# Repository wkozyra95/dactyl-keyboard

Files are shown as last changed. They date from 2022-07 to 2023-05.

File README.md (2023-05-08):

# The Dactyl-ManuForm Keyboard

This fork is just for my personal customizations, it removes a lot of features of the [original project](https://github.com/tshort/dactyl-keyboard).

## Third iteration



**.scad** and **.stl** files can be found in [./things/03-iteration](/things/03-iteration).

- `right.stl` and `left.stl` represents 2 halves of split keyboard. IO of each part includes:
  - Output to expose usb-c or micro usb port for charging and flushing firmware.
  - 2-position switch for controlling power for keyboard.
  - Reset button.
- `dongle.stl` is a case for nice nano that is main controller (nice!nano v2.0) for both parts of the keyboards.
- `plate.dxf` describes 2D shape of a bottom plate that case is mounted on.
- `platev2.dxf` plate variant with a cut-out in the middle intended for charging coil for wireless charging.

Communication between all the parts is handled by a nice!nano controller in a dongle. Both parts of the keyboard have it's own nice!nano controllers that connect to a dongle via bluetooth. This approach enables using this keyboard wirelessly before bluetooth is on e.g. in BIOS, or to provide LUKS password.

Power for all parts is provided via usb, but both keyboard halves also include batteries that should enable few weeks of work without recharging. Main controller has to always listen for bluetooth communication from other parts. This is increasing power usage when compared to secondary parts, so it's best to use dongle for that, which is always is connected via usb.

## Second iteration



**.scad** and **.stl** files can be found in [./things/02-iteration](/things/02-iteration).

## First iteration



**.scad** and **.stl** files can be found in [./things/01-iteration](/things/01-iteration).

# README from original repo

This is a fork of the [Dactyl](https://github.com/adereth/dactyl-keyboard), a parameterized, split-hand, concave, columnar, ergonomic keyboard.

Imgur

The main change is that the thumb cluster was adapted from the [ManuForm keyboard](https://github.com/jeffgran/ManuForm) ([geekhack](https://geekhack.org/index.php?topic=46015.0)). The walls were changed to just drop to the floor. The keyboard is paramaterized to allow adjusting the following:

* Rows: 4 - 6
* Columns: 5 and up
* Row curvature
* Column curvature
* Row tilt (tenting)
* Column tilt
* Column offsets
* Height

I built a 4x5 version (40% size) for myself. The default has a bit more tenting than the Dactyl. See the following model files for configurations that may be most common:

* [40% size, (4x5)](https://github.com/tshort/dactyl-keyboard/blob/master/things/right-4x5.stl)
* [60% size, (5x6)](https://github.com/tshort/dactyl-keyboard/blob/master/things/right-5x6.stl)

## Assembly

### Generating a Design

**Setting up the Clojure environment**
* [Install the Clojure runtime](https://clojure.org)
* [Install the Leiningen project manager](http://leiningen.org/)
* [Install OpenSCAD](http://www.openscad.org/)

**Generating the design**
* Run `lein repl`
* Load the file `(load-file "src/dactyl_keyboard/dactyl.clj")`
* This will regenerate the `things/*.scad` files
* Use OpenSCAD to open a `.scad` file.
* Make changes to design, repeat `load-file`, OpenSCAD will watch for changes and rerender.
* When done, use OpenSCAD to export STL files

**Tips**
* [Some other ways to evaluate the clojure design file](http://stackoverflow.com/a/28213489)
* [Example designing with clojure](http://adereth.github.io/blog/2014/04/09/3d-printing-with-clojure/)

### Printing
Pregenerated STL files are available in the [things/](things/) directory.
When a model is generated, it also generates a `.scad` model for a bottom plate.
This can be exported to a DXF file in OpenSCAD.
The [things/](things/) directory also has DXF files for the bottom plate.
When laser cut, some of the inside cuts will need to be removed.

This model can be tricky to print.
It's wide, so I've had problems with PLA on a Makerbot with edges warping.
This can cause the printer to think its head is jammed.
Even if it successfully prints, warping can cause problems.
On one print, the RJ-9 holder was squished, so I had to cut down my connector to fit.

If printed at Shapeways or other professional shops, I would not expect such problems.

### Thingiverse

[The 4x5 STL left/right pair](https://www.thingiverse.com/thing:2349390) from the [things/](things/) directory is in the thingiverse for public printing

### Wiring

Here are materials I used for wiring.

* Two Arduino Pro Micros
* [Heat-set inserts](https://www.mcmaster.com/#94180a331/=16yfrx1)
* [M3 wafer-head screws, 5mm](http://www.metricscrews.us/index.php?main_page=product_info&cPath=155_185&products_id=455)
* [Copper tape](https://www.amazon.com/gp/product/B009KB86BU)
* [#32 magnet wire](https://www.amazon.com/gp/product/B00LV909HI)
* [#30 wire](https://www.amazon.com/gp/product/B00GWFECWO)
* [3-mm cast acrylic](http://www.mcmaster.com/#acrylic/=144mfom)
* [Veroboard stripboard](https://www.amazon.com/gp/product/B008CPVMMU)
* [1N4148 diodes](https://www.amazon.com/gp/product/B00LQPY0Y0)
* [Female RJ-9 connectors](https://www.amazon.com/gp/product/B01HU7BVDU/)

I wired one half using the traditional approach of using the legs of a diode to form the row connections.
(I'm not great at soldering, so this was challenging for me.)
For this side, I used magnet wire to wire columns. That worked okay.
The magnet wire is small enough, it wants to move around, and it's hard to tell if you have a good connection.

Imgur

For another half, I used stripboard for the row connections.
This allowed me to presolder all of the diodes.
Then, I hot-glued this in place and finished the soldering of the other diode ends.
I like this approach quite a lot.
Connections for the diodes were much easier with one end fixed down.
On this half, I also used copper tape to connect columns.
This worked a bit better than the magnet wire for me.
For a future version, I may try just bare tinned copper wire for columns (something like #20).
With the stripboard, it's pretty easy keeping row and column connections separate.

Imgur

Note that a telephone handset cable has leads that are reversed, so take this into account when connecting these leads to the controller.

The 3D printed part is the main keyboard.
You can attach a bottom plate with screws.
The case has holes for heat-set inserts designed to hold 3- to 6-mm long M3 screws.
Then, I used wafer-head screws to connect a bottom plate.
If wires aren't dangling, a bottom plate may not be needed.
You need something on the bottom to keep the keyboard from sliding around.
Without a plate, you could use a rubber pad, or you could dip the bottom of the keyboard in PlastiDip.

For more photos of the first complete wiring of v0.4, see [Imgur](http://imgur.com/a/v9eIO).

This is how the rows/columns wire to the keys and the ProMicro
Wire Diagram

#### Alternative row-driven wiring diagram for ProMicro:

NOTE: you also make sure the firmware is set up correctly (ex: change row pins with col pins)

Left Wire Diagram

Left Wire Diagram

### Firmware

Firmware goes hand in hand with how you wire the circuit.
I adapted the QMK firmware [here](https://github.com/tshort/qmk_firmware/tree/master/keyboards/dactyl-manuform).
This allows each side to work separately or together.
This site also shows connections for the Arduino Pro Micro controllers.

## License

Copyright © 2015-2017 Matthew Adereth and Tom Short

The source code for generating the models (everything excluding the [things/](things/) and [resources/](resources/) directories is distributed under the [GNU AFFERO GENERAL PUBLIC LICENSE Version 3](LICENSE).  The generated models and PCB designs are distributed under the [Creative Commons Attribution-NonCommercial-ShareAlike License Version 3.0](LICENSE-models).

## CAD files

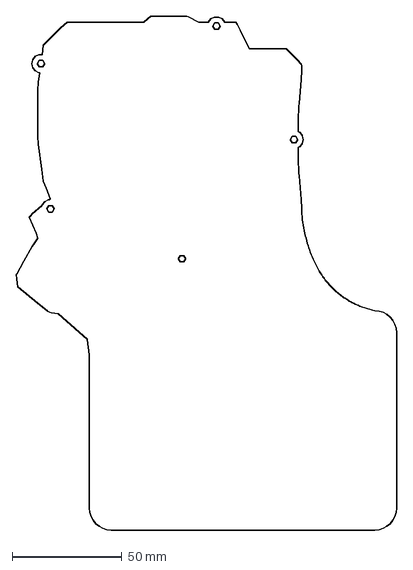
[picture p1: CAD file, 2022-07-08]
things/01-iteration/plate-v2.dxf
173.3 x 234.3 mm

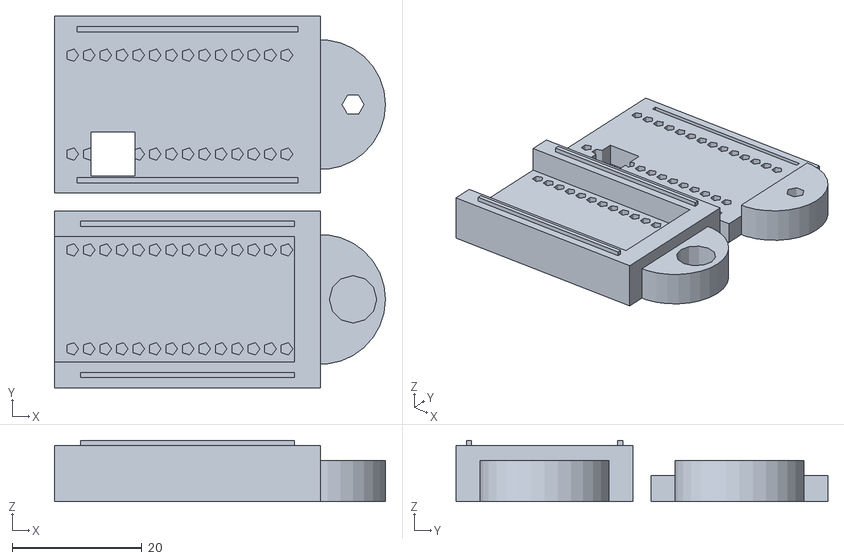
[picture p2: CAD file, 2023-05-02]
things/03-iteration/donglev2.stl
51.0 x 57.3 x 9.44

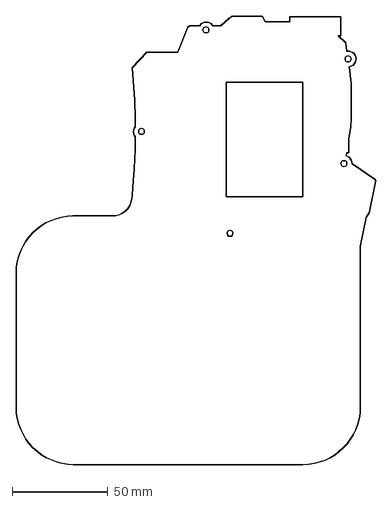
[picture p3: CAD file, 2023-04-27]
things/03-iteration/platev2.dxf
188.2 x 234.3 mm

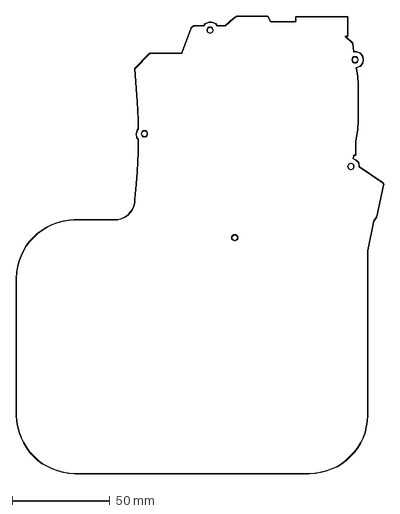
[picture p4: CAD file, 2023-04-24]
things/03-iteration/plate.dxf
188.2 x 234.3 mm

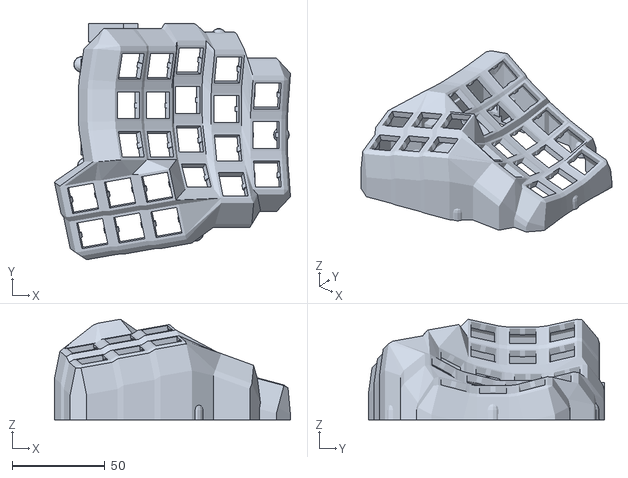
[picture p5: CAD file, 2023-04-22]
things/03-iteration/right.stl
127.4 x 127.7 x 54.3

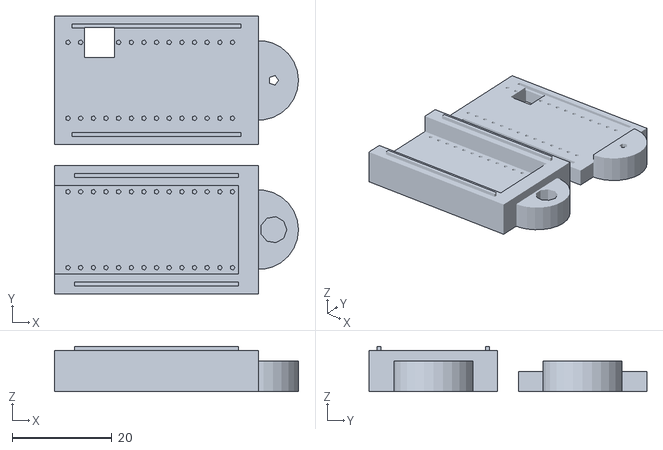
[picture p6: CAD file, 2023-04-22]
things/03-iteration/dongle.stl
49.0 x 55.8 x 9.04

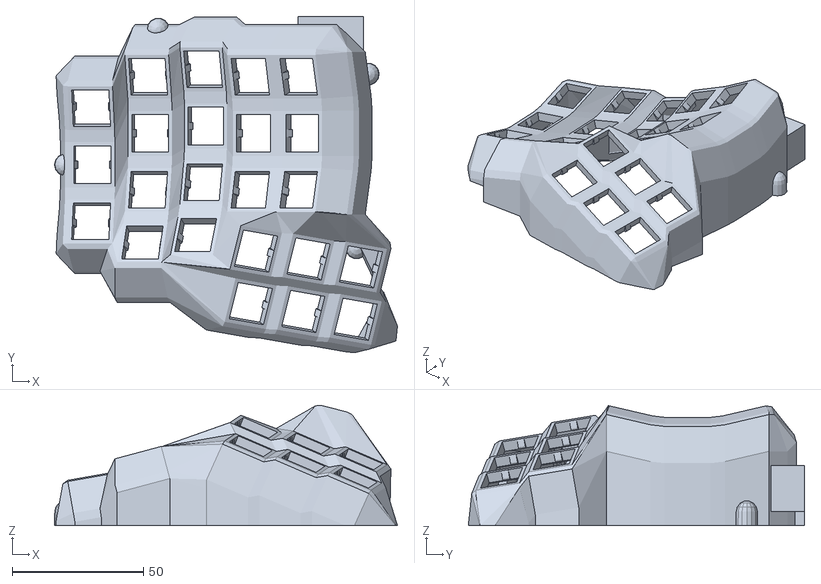
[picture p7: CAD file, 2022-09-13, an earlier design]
things/02-iteration/left.stl
130.8 x 128.3 x 45.8

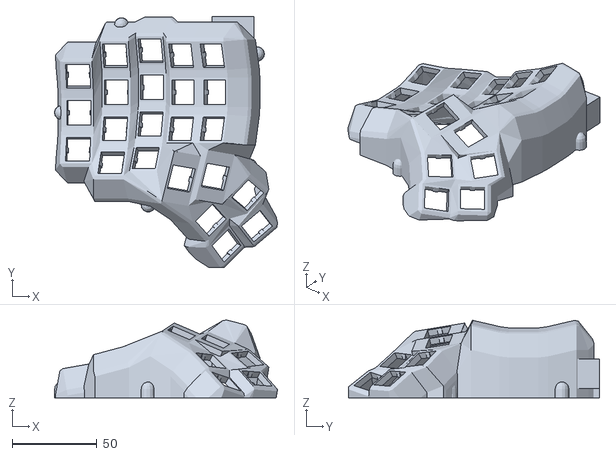
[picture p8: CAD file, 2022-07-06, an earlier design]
things/left.stl
131.5 x 147.9 x 45.8

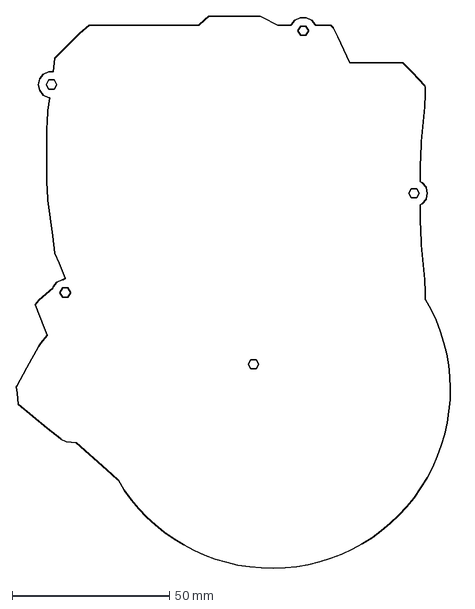
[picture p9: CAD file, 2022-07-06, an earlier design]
things/01-iteration/plate-v1.dxf
140.6 x 175.7 mm

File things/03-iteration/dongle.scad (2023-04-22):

union () {
  translate ([0, 30, 0]) {
    union () {
      translate ([0, 0, 3.06]) {
        translate ([41/2, 0, 0]) {
          difference () {
            union () {
              cylinder (h=6.12, r=8, center=true);
            }
            translate ([3, 0, 0]) {
              cylinder (h=100, r=1, center=true);
            }
            translate ([-50, 0, 0]) {
              cube ([100, 100, 100], center=true);
            }
          }
        }
      }
      difference () {
        translate ([0, 0, 2]) {
          difference () {
            cube ([41, 25.8, 4], center=true);
            translate ([0, 0, 1.2]) {
              union () {
                translate ([0, 10.9, 0.4]) {
                  cube ([34, 0.8500000000000001, 0.8500000000000001], center=true);
                }
                translate ([0, -10.9, 0.4]) {
                  cube ([34, 0.8500000000000001, 0.8500000000000001], center=true);
                }
              }
            }
            translate ([-11.5, 7.62, 0]) {
              cube ([6, 6, 10], center=true);
            }
          }
        }
        translate ([0, 0, 2.2025]) {
          union () {
            translate ([0, 7.62, 0]) {
              union () {
                translate ([-17.78, 0, 0]) {
                  cylinder (h=3.6049999999999995, r=0.5, center=true);
                }
                translate ([-15.24, 0, 0]) {
                  cylinder (h=3.6049999999999995, r=0.5, center=true);
                }
                translate ([-12.7, 0, 0]) {
                  cylinder (h=3.6049999999999995, r=0.5, center=true);
                }
                translate ([-10.16, 0, 0]) {
                  cylinder (h=3.6049999999999995, r=0.5, center=true);
                }
                translate ([-7.62, 0, 0]) {
                  cylinder (h=3.6049999999999995, r=0.5, center=true);
                }
                translate ([-5.08, 0, 0]) {
                  cylinder (h=3.6049999999999995, r=0.5, center=true);
                }
                translate ([-2.54, 0, 0]) {
                  cylinder (h=3.6049999999999995, r=0.5, center=true);
                }
                translate ([0.0, 0, 0]) {
                  cylinder (h=3.6049999999999995, r=0.5, center=true);
                }
                translate ([2.54, 0, 0]) {
                  cylinder (h=3.6049999999999995, r=0.5, center=true);
                }
                translate ([5.08, 0, 0]) {
                  cylinder (h=3.6049999999999995, r=0.5, center=true);
                }
                translate ([7.62, 0, 0]) {
                  cylinder (h=3.6049999999999995, r=0.5, center=true);
                }
                translate ([10.16, 0, 0]) {
                  cylinder (h=3.6049999999999995, r=0.5, center=true);
                }
                translate ([12.7, 0, 0]) {
                  cylinder (h=3.6049999999999995, r=0.5, center=true);
                }
                translate ([15.24, 0, 0]) {
                  cylinder (h=3.6049999999999995, r=0.5, center=true);
                }
              }
            }
            translate ([0, -7.62, 0]) {
              union () {
                translate ([-17.78, 0, 0]) {
                  cylinder (h=3.6049999999999995, r=0.5, center=true);
                }
                translate ([-15.24, 0, 0]) {
                  cylinder (h=3.6049999999999995, r=0.5, center=true);
                }
                translate ([-12.7, 0, 0]) {
                  cylinder (h=3.6049999999999995, r=0.5, center=true);
                }
                translate ([-10.16, 0, 0]) {
                  cylinder (h=3.6049999999999995, r=0.5, center=true);
                }
                translate ([-7.62, 0, 0]) {
                  cylinder (h=3.6049999999999995, r=0.5, center=true);
                }
                translate ([-5.08, 0, 0]) {
                  cylinder (h=3.6049999999999995, r=0.5, center=true);
                }
                translate ([-2.54, 0, 0]) {
                  cylinder (h=3.6049999999999995, r=0.5, center=true);
                }
                translate ([0.0, 0, 0]) {
                  cylinder (h=3.6049999999999995, r=0.5, center=true);
                }
                translate ([2.54, 0, 0]) {
                  cylinder (h=3.6049999999999995, r=0.5, center=true);
                }
                translate ([5.08, 0, 0]) {
                  cylinder (h=3.6049999999999995, r=0.5, center=true);
                }
                translate ([7.62, 0, 0]) {
                  cylinder (h=3.6049999999999995, r=0.5, center=true);
                }
                translate ([10.16, 0, 0]) {
                  cylinder (h=3.6049999999999995, r=0.5, center=true);
                }
                translate ([12.7, 0, 0]) {
                  cylinder (h=3.6049999999999995, r=0.5, center=true);
                }
                translate ([15.24, 0, 0]) {
                  cylinder (h=3.6049999999999995, r=0.5, center=true);
                }
              }
            }
          }
        }
      }
    }
  }
  union () {
    translate ([0, 0, 3.06]) {
      translate ([41/2, 0, 0]) {
        difference () {
          union () {
            cylinder (h=6.12, r=8, center=true);
          }
          translate ([3, 0, 1]) {
            cylinder (h=6.12, r=2.655, center=true);
          }
          translate ([-50, 0, 0]) {
            cube ([100, 100, 100], center=true);
          }
        }
      }
    }
    translate ([0, 0, 6.12]) {
      union () {
        translate ([0, 10.9, 0]) {
          cube ([41, 4, 4.24], center=true);
        }
        translate ([0, 10.9, 2.52]) {
          cube ([33, 0.8, 0.8], center=true);
        }
        translate ([0, -10.9, 0]) {
          cube ([41, 4, 4.24], center=true);
        }
        translate ([0, -10.9, 2.52]) {
          cube ([33, 0.8, 0.8], center=true);
        }
        translate ([37/2, 0, 0]) {
          cube ([4, 25.8, 4.24], center=true);
        }
      }
    }
    difference () {
      translate ([0, 0, 2]) {
        cube ([41, 25.8, 4], center=true);
      }
      translate ([0, 0, 2.2025]) {
        union () {
          translate ([0, 7.62, 0]) {
            union () {
              translate ([-17.78, 0, 0]) {
                cylinder (h=3.6049999999999995, r=0.5, center=true);
              }
              translate ([-15.24, 0, 0]) {
                cylinder (h=3.6049999999999995, r=0.5, center=true);
              }
              translate ([-12.7, 0, 0]) {
                cylinder (h=3.6049999999999995, r=0.5, center=true);
              }
              translate ([-10.16, 0, 0]) {
                cylinder (h=3.6049999999999995, r=0.5, center=true);
              }
              translate ([-7.62, 0, 0]) {
                cylinder (h=3.6049999999999995, r=0.5, center=true);
              }
              translate ([-5.08, 0, 0]) {
                cylinder (h=3.6049999999999995, r=0.5, center=true);
              }
              translate ([-2.54, 0, 0]) {
                cylinder (h=3.6049999999999995, r=0.5, center=true);
              }
              translate ([0.0, 0, 0]) {
                cylinder (h=3.6049999999999995, r=0.5, center=true);
              }
              translate ([2.54, 0, 0]) {
                cylinder (h=3.6049999999999995, r=0.5, center=true);
              }
              translate ([5.08, 0, 0]) {
                cylinder (h=3.6049999999999995, r=0.5, center=true);
              }
              translate ([7.62, 0, 0]) {
                cylinder (h=3.6049999999999995, r=0.5, center=true);
              }
              translate ([10.16, 0, 0]) {
                cylinder (h=3.6049999999999995, r=0.5, center=true);
              }
              translate ([12.7, 0, 0]) {
                cylinder (h=3.6049999999999995, r=0.5, center=true);
              }
              translate ([15.24, 0, 0]) {
                cylinder (h=3.6049999999999995, r=0.5, center=true);
              }
            }
          }
          translate ([0, -7.62, 0]) {
            union () {
              translate ([-17.78, 0, 0]) {
                cylinder (h=3.6049999999999995, r=0.5, center=true);
              }
              translate ([-15.24, 0, 0]) {
                cylinder (h=3.6049999999999995, r=0.5, center=true);
              }
              translate ([-12.7, 0, 0]) {
                cylinder (h=3.6049999999999995, r=0.5, center=true);
              }
              translate ([-10.16, 0, 0]) {
                cylinder (h=3.6049999999999995, r=0.5, center=true);
              }
              translate ([-7.62, 0, 0]) {
                cylinder (h=3.6049999999999995, r=0.5, center=true);
              }
              translate ([-5.08, 0, 0]) {
                cylinder (h=3.6049999999999995, r=0.5, center=true);
              }
              translate ([-2.54, 0, 0]) {
                cylinder (h=3.6049999999999995, r=0.5, center=true);
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

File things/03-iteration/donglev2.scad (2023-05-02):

union () {
  translate ([0, 30, 0]) {
    union () {
      translate ([0, 0, 3.16]) {
        translate ([41/2, 0, 0]) {
          difference () {
            union () {
              cylinder (h=6.32, r=10, center=true);
            }
            translate ([5, 0, 0]) {
              cylinder (h=100, r=1.7, center=true);
            }
            translate ([-50, 0, 0]) {
              cube ([100, 100, 100], center=true);
            }
          }
        }
      }
      difference () {
        translate ([0, 0, 2]) {
          difference () {
            cube ([41, 27.3, 4], center=true);
            translate ([0, 0, 1.2]) {
              union () {
                translate ([0, 11.65, 0.4]) {
                  cube ([34, 0.8500000000000001, 1.0], center=true);
                }
                translate ([0, -11.65, 0.4]) {
                  cube ([34, 0.8500000000000001, 1.0], center=true);
                }
              }
            }
            translate ([-11.5, -7.62, 0]) {
              cube ([6.8, 6.8, 10], center=true);
            }
          }
        }
        translate ([0, 0, 2.3025]) {
          union () {
            translate ([0, 7.62, 0]) {
              union () {
                translate ([-17.78, 0, 0]) {
                  cylinder (h=3.4049999999999994, r=1, center=true);
                }
                translate ([-15.24, 0, 0]) {
                  cylinder (h=3.4049999999999994, r=1, center=true);
                }
                translate ([-12.7, 0, 0]) {
                  cylinder (h=3.4049999999999994, r=1, center=true);
                }
                translate ([-10.16, 0, 0]) {
                  cylinder (h=3.4049999999999994, r=1, center=true);
                }
                translate ([-7.62, 0, 0]) {
                  cylinder (h=3.4049999999999994, r=1, center=true);
                }
                translate ([-5.08, 0, 0]) {
                  cylinder (h=3.4049999999999994, r=1, center=true);
                }
                translate ([-2.54, 0, 0]) {
                  cylinder (h=3.4049999999999994, r=1, center=true);
                }
                translate ([0.0, 0, 0]) {
                  cylinder (h=3.4049999999999994, r=1, center=true);
                }
                translate ([2.54, 0, 0]) {
                  cylinder (h=3.4049999999999994, r=1, center=true);
                }
                translate ([5.08, 0, 0]) {
                  cylinder (h=3.4049999999999994, r=1, center=true);
                }
                translate ([7.62, 0, 0]) {
                  cylinder (h=3.4049999999999994, r=1, center=true);
                }
                translate ([10.16, 0, 0]) {
                  cylinder (h=3.4049999999999994, r=1, center=true);
                }
                translate ([12.7, 0, 0]) {
                  cylinder (h=3.4049999999999994, r=1, center=true);
                }
                translate ([15.24, 0, 0]) {
                  cylinder (h=3.4049999999999994, r=1, center=true);
                }
              }
            }
            translate ([0, -7.62, 0]) {
              union () {
                translate ([-17.78, 0, 0]) {
                  cylinder (h=3.4049999999999994, r=1, center=true);
                }
                translate ([-15.24, 0, 0]) {
                  cylinder (h=3.4049999999999994, r=1, center=true);
                }
                translate ([-12.7, 0, 0]) {
                  cylinder (h=3.4049999999999994, r=1, center=true);
                }
                translate ([-10.16, 0, 0]) {
                  cylinder (h=3.4049999999999994, r=1, center=true);
                }
                translate ([-7.62, 0, 0]) {
                  cylinder (h=3.4049999999999994, r=1, center=true);
                }
                translate ([-5.08, 0, 0]) {
                  cylinder (h=3.4049999999999994, r=1, center=true);
                }
                translate ([-2.54, 0, 0]) {
                  cylinder (h=3.4049999999999994, r=1, center=true);
                }
                translate ([0.0, 0, 0]) {
                  cylinder (h=3.4049999999999994, r=1, center=true);
                }
                translate ([2.54, 0, 0]) {
                  cylinder (h=3.4049999999999994, r=1, center=true);
                }
                translate ([5.08, 0, 0]) {
                  cylinder (h=3.4049999999999994, r=1, center=true);
                }
                translate ([7.62, 0, 0]) {
                  cylinder (h=3.4049999999999994, r=1, center=true);
                }
                translate ([10.16, 0, 0]) {
                  cylinder (h=3.4049999999999994, r=1, center=true);
                }
                translate ([12.7, 0, 0]) {
                  cylinder (h=3.4049999999999994, r=1, center=true);
                }
                translate ([15.24, 0, 0]) {
                  cylinder (h=3.4049999999999994, r=1, center=true);
                }
              }
            }
          }
        }
      }
    }
  }
  union () {
    translate ([0, 0, 3.16]) {
      translate ([41/2, 0, 0]) {
        difference () {
          union () {
            cylinder (h=6.32, r=10, center=true);
          }
          translate ([5, 0, 1]) {
            cylinder (h=6.32, r=3.655, center=true);
          }
          translate ([-50, 0, 0]) {
            cube ([100, 100, 100], center=true);
          }
        }
      }
    }
    translate ([0, 0, 6.32]) {
      union () {
        translate ([0, 11.65, 0]) {
          cube ([41, 4, 4.640000000000001], center=true);
        }
        translate ([0, 11.65, 2.72]) {
          cube ([33, 0.8, 0.8], center=true);
        }
        translate ([0, -11.65, 0]) {
          cube ([41, 4, 4.640000000000001], center=true);
        }
        translate ([0, -11.65, 2.72]) {
          cube ([33, 0.8, 0.8], center=true);
        }
        translate ([37/2, 0, 0]) {
          cube ([4, 27.3, 4.640000000000001], center=true);
        }
      }
    }
    difference () {
      translate ([0, 0, 2]) {
        cube ([41, 27.3, 4], center=true);
      }
      translate ([0, 0, 2.3025]) {
        union () {
          translate ([0, 7.62, 0]) {
            union () {
              translate ([-17.78, 0, 0]) {
                cylinder (h=3.4049999999999994, r=1, center=true);
              }
              translate ([-15.24, 0, 0]) {
                cylinder (h=3.4049999999999994, r=1, center=true);
              }
              translate ([-12.7, 0, 0]) {
                cylinder (h=3.4049999999999994, r=1, center=true);
              }
              translate ([-10.16, 0, 0]) {
                cylinder (h=3.4049999999999994, r=1, center=true);
              }
              translate ([-7.62, 0, 0]) {
                cylinder (h=3.4049999999999994, r=1, center=true);
              }
              translate ([-5.08, 0, 0]) {
                cylinder (h=3.4049999999999994, r=1, center=true);
              }
              translate ([-2.54, 0, 0]) {
                cylinder (h=3.4049999999999994, r=1, center=true);
              }
              translate ([0.0, 0, 0]) {
                cylinder (h=3.4049999999999994, r=1, center=true);
              }
              translate ([2.54, 0, 0]) {
                cylinder (h=3.4049999999999994, r=1, center=true);
              }
              translate ([5.08, 0, 0]) {
                cylinder (h=3.4049999999999994, r=1, center=true);
              }
              translate ([7.62, 0, 0]) {
                cylinder (h=3.4049999999999994, r=1, center=true);
              }
              translate ([10.16, 0, 0]) {
                cylinder (h=3.4049999999999994, r=1, center=true);
              }
              translate ([12.7, 0, 0]) {
                cylinder (h=3.4049999999999994, r=1, center=true);
              }
              translate ([15.24, 0, 0]) {
                cylinder (h=3.4049999999999994, r=1, center=true);
              }
            }
          }
          translate ([0, -7.62, 0]) {
            union () {
              translate ([-17.78, 0, 0]) {
                cylinder (h=3.4049999999999994, r=1, center=true);
              }
              translate ([-15.24, 0, 0]) {
                cylinder (h=3.4049999999999994, r=1, center=true);
              }
              translate ([-12.7, 0, 0]) {
                cylinder (h=3.4049999999999994, r=1, center=true);
              }
              translate ([-10.16, 0, 0]) {
                cylinder (h=3.4049999999999994, r=1, center=true);
              }
              translate ([-7.62, 0, 0]) {
                cylinder (h=3.4049999999999994, r=1, center=true);
              }
              translate ([-5.08, 0, 0]) {
                cylinder (h=3.4049999999999994, r=1, center=true);
              }
              translate ([-2.54, 0, 0]) {
                cylinder (h=3.4049999999999994, r=1, center=true);
              }
              translate ([0.0, 0, 0]) {
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

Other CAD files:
things/03-iteration/left.stl
things/01-iteration/right.stl
things/02-iteration/right.stl
things/right.stl
things/03-iteration/left.scad
things/03-iteration/right.scad
things/01-iteration/left.scad
things/01-iteration/right.scad
things/02-iteration/left.scad
things/02-iteration/right.scad

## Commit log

2022-07-06 first iteration
    [left.scad, left.stl, plate-v1.dxf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]
2022-07-08 update bottom plate to fit wrist support
    [plate-v2.dxf]
2022-09-11 second iteration
    [left.scad, right.scad]
2022-09-13 generate stl files
    [left.stl, right.stl]
2023-04-22 add third revision
    [dongle.scad, dongle.stl, left.scad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]
2023-04-24 add plate
    [plate.dxf]
2023-04-27 add alternative plate with cutout
    [platev2.dxf]
2023-04-27 add donglev2
    - fixes size of a reset switch
    - increase size of a screw insert and screw hole
    - increase radius of inserts for breakout board pins
    - increase controller width
    [donglev2.scad, donglev2.stl]
2023-05-02 adjust donglev2 dimensions
    [donglev2.scad, donglev2.stl]
